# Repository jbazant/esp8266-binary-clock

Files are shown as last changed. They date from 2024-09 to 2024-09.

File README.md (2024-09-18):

# WEMOS D1 mini Binary clock

This is a private project. No support is provided. No input expected. Also as soon as I finish 1st version, I will
probably not work on it anymore.

Esp8266 based, IKEA Skadis mounted, NTP synchronized, "smart" binary clock with temperature and humidity sensor.

Binary clock based on a WEMOS D1 mini and a 8x8 LED matrix. Shows the seconds, minutes, hours, day in month, day in
week, month, lunar phase and last two decimal digits of year in binary format.
Also uses a DHT sensor to show the temperature and humidity.
Time is synchronized via NTP.

Two buttons allow to disable display and set the brightness.

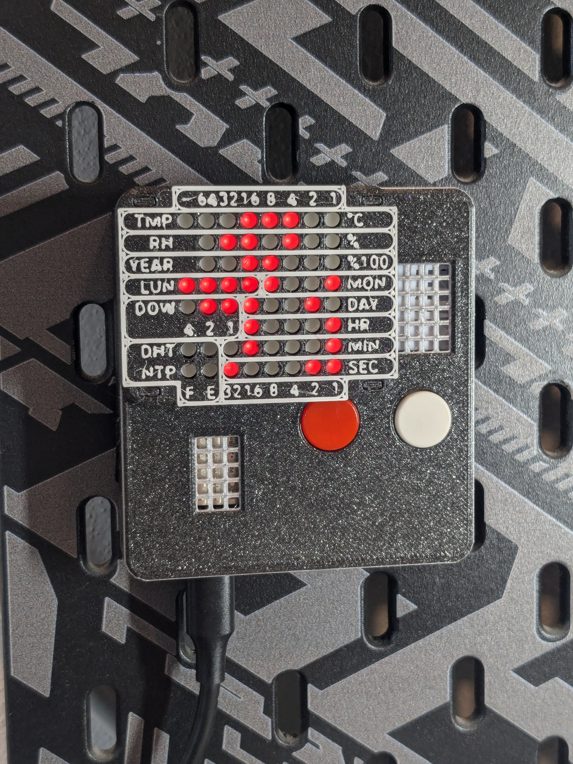
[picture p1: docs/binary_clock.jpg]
Binary clock


## How to read the clock

- Columns correspond to bits. Read them as (from right to left): 1, 2, 4, 8, 16, 32, 64.
- 8th bit is used for temperature as a sign bit (0 - positive, 1 - negative).
- Some rows have different meaning for top-most bits, but it should be obvious, once you get the idea.
- Labels on display cover should guide you.

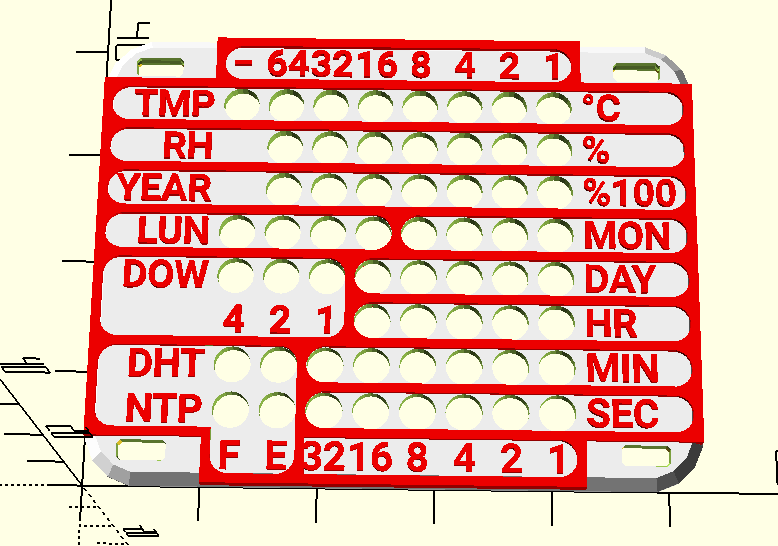
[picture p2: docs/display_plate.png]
Cover with labels


### Rows

Rows from top to bottom:

- **1st row**: temperature (in Celsius) - 8th bit is a sign bit (0 - positive, 1 - negative)
- **2nd row**: relative humidity (in %) - 8th bit is not used (and it is also not visible on the display)
- **3rd row**: years - last two decimal digits (or year % 100, if you prefer), 8th bit is not used
  plate place is occupied by temperature labels)
- **4th row**:
    - Bits 1 - 4: months (1 = January, 12 = December)
    - Bits 5 - 8: lunar phase (see description below)
- **5th row**:
    - Bits 1 - 5: day in month
    - Bits 6 - 8: day of week - read from right to left - 6th bit means 1, 8th bit means 4 (1 = Monday, 7 = Sunday)
- **6th row**:
    - Bits 1 - 5: hours (24h format)
    - Bits 6 - 8: not used (and on the display plate place is occupied by day of week labels)
- **7th row**:
    - Bits 1 - 6: minutes
    - Bits 7 - 8: status bits for DHT sensor. 7 - last read failed (**E**rror), 8 - reading sensor in progress (**F**
      etching)
- **8th row**:
    - Bits 1 - 6: seconds
    - Bits 7 - 8: status bits for NTP synchronization. 7 - last synchronization failed (**E**rror), 8 - time
      synchronization in progress (**F**etching)

### Lunar phase

| Bits 5 - 8 | Lunar phase | 🌝 |
|---|---|----|
| 0000 | New moon | 🌑 |
| 0001 | Waxing crescent | 🌒 |
| 0011 | First quarter | 🌓 |
| 0111 | Waxing gibbous  | 🌔 |
| 1111 | Full moon | 🌕 |
| 1110 | Waning gibbous  | 🌖 |
| 1100 | Last quarter | 🌗 |
| 1000 | Waning crescent | 🌘 |

Photo of the clock shows: Wednesday, 18th of September 2024, 12:17:35, full moon, 28°C, 52% relative humidity.

## Hardware

- WEMOS D1 mini
- 8x8 LED matrix with MAX7219 controller (FC-16)
- DHT22 sensor
- 2 buttons
- 4 pull-up 10kOhm resistors (2 for the buttons, 1 for the DHT sensor and 1 for reset pin)

## Software

The software is written as arduino project mostly in C++ and can be found in the `esp8266-binary-clock` folder (to
satisfy arduino project structure).

### Dependencies

- **DHT library** by Bert Melis ([GitHub](https://github.com/bertmelis/DHT))
- **NTP library** by Stefan Staub ([GitHub](https://github.com/sstaub/NTP))
- **LedController** library by Noah Kirschmann ([GitHub](https://github.com/noah1510/LedController))
- **moonPhaser** library by Steve Sienkowski ([GitHub](https://github.com/steve-sienk/moonPhaser-avr0))

### Configuration

- Create `secrets.h` in the `esp8266-binary-clock` and specify your WiFi credentials. (see `secrets.h.example`)
- Adjust `CONFIGURATION` section and `initTimezoneAndDST` method in `esp8266-binary-clock.ino` to your needs (or just
  leave as is).
    - `DHT_INTERVAL_S` - interval for reading DHT sensor (in seconds), default 1 minute
    - `NTP_INTERVAL_S` - interval for NTP synchronization (in seconds), default 12 hours

## PCB

The PCB is designed in KiCad and can be found in the `pcb` folder. Size of the PCB board is 66 x58 mm with LED matrix
and DHT22 sensor overhanging the board.
Board is actually pretty simple and uses just one Cu layer and 0.5mm clearance between tracks. You need to use 1.6mm PCB
thickness or adjust the case (bottom part).

## Case

The case is designed in OpenScad and can be found in the `case` folder. Optimized (well as much as I was able to...) for
FDM 3D printing.

- optimized for 0.4mm nozzle and 0.2mm layer height
- tested with PLA
- no supports
- 2 perimeters and 15% infill is more than enough

Case is divided into 3 parts:

- bottom (`case_bottom.scad`)
- top (`case_top.scad`)
- display cover (`display_plate.scad`)

One can render all parts with the `case.scad` file.

All the parts should snap together without any screws or glue.

### Dependencies

- **BOSL library** by Revar Desmera ([GitHub](https://github.com/revarbat/BOSL)).
- **Roboto** (bold) font by Christian Robertson ([Google fonts](https://fonts.google.com/specimen/Roboto0)).

### Case bottom

Case is printed with supports that are included in the model. Do not add supports in slicer! After printing, remove
the "triangle" simply by tilting it back and forth
and "mouse ears" with a knife.

Assembled PCB (optimized for 1.6mm height) should fit into the model without any screws or glue. Some force is needed to
snap it in.

### Case top

- *(Optional)* color change at heights:
    - Start with color for "ventilation" grids.
    - Change color at 1.4mm for the base one.

### Display cover

- Use some pretty contrast colors for the display cover. Change filament color at the height of 1.2mm.
- *(Optional)* Use nozzle of 0.25mm for better readability of the labels.

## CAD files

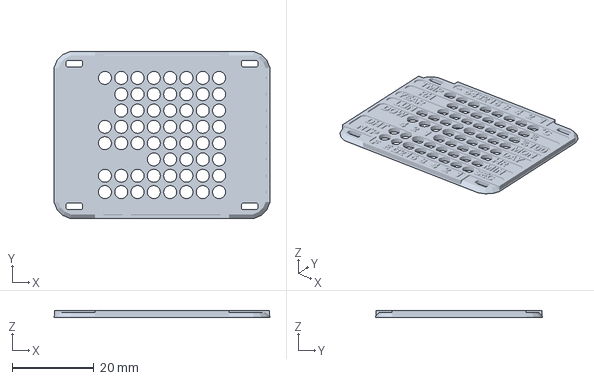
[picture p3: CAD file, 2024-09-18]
case/display_plate.3mf
53.0 x 41.0 x 1.60 mm

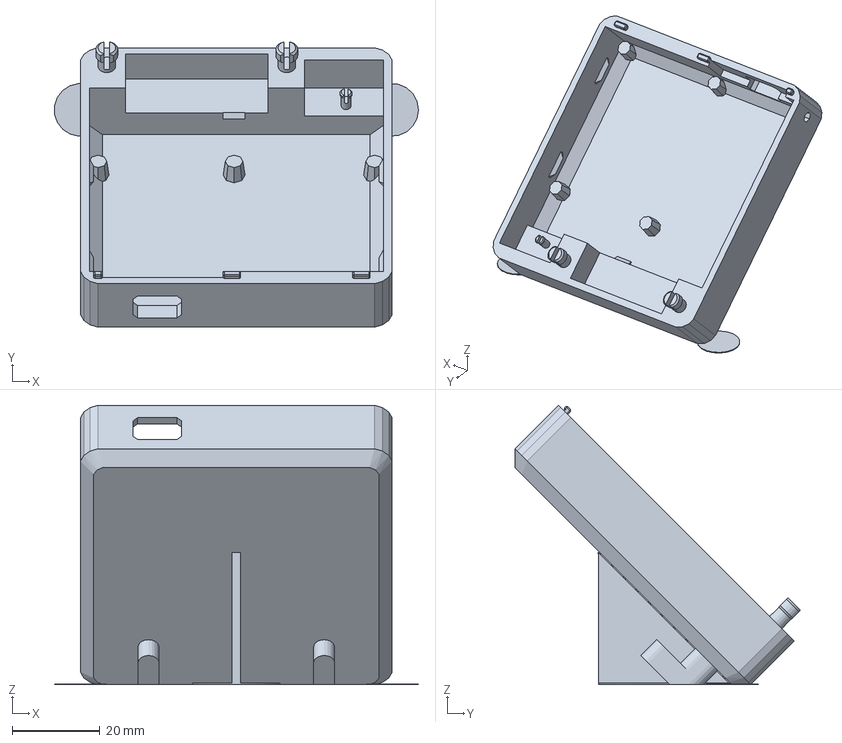
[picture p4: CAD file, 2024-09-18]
case/case_bottom.3mf
82.9 x 65.0 x 63.6 mm

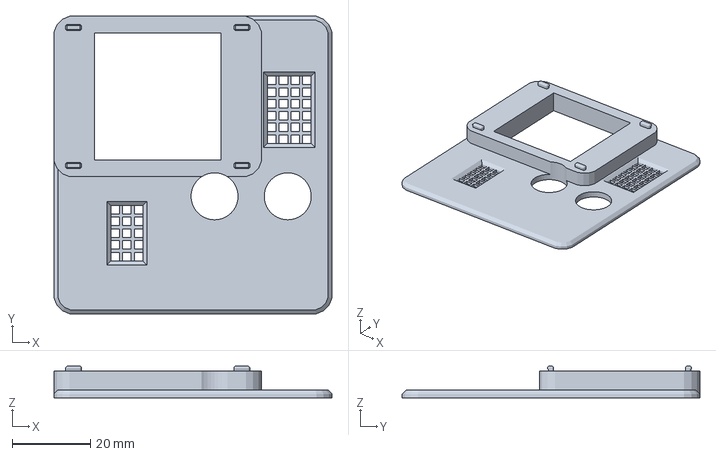
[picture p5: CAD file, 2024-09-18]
case/case_top.3mf
71.0 x 76.0 x 8.10 mm

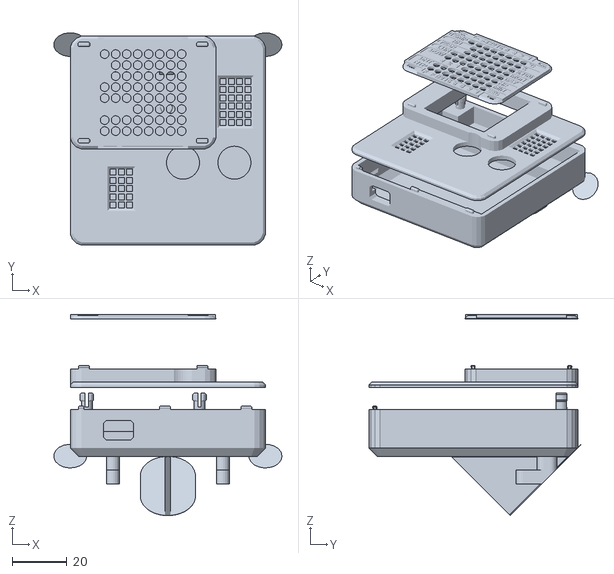
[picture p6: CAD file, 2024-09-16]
case/case.stl
82.9 x 77.2 x 73.2

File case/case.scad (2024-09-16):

use <BOSL/transforms.scad>
use <case_top.scad>
use <case_bottom.scad>
use <display_plate.scad>

// --- global configuration ---
// (actually do not mess with it)
w=71;
l=76;
f=5;

// --- render ---
zdistribute(25) {
    case_bottom(w, l, f);
    case_top(w, l, f);
    translate([0, 35, -10]) display_plate(f, "Roboto:style=Bold");
}

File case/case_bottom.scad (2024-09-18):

include <BOSL/constants.scad>
use <BOSL/transforms.scad>
use <BOSL/shapes.scad>
include <skadis.scad>
use <locks.scad>

// --- global configuration ---
// (actually do not mess with it)
w=71;
l=76;
f=5;

// --- render ---
xrot(-45) 
    case_bottom(w, l, f);

// --- modules ----
module case_bottom(w, l, f) {
    h1=8;
    h2=9;
    pcb_l=59;
    pcb_w=w-4;
    
    module custom_print_support() {
        color([.5, .5, .5], .7) union() {
            translate([w/2, 3*l/4, 0]) {
                translate([0, 5, 10.3]) rotate([45, 0, 180])         
                    right_triangle(
                        [2, 30, 30], 
                        orient=ORIENT_X, align=V_DOWN
                    );
                
                for (ty=[-l/3 : 4 : l/4]) {
                    translate([0, ty, 1]) xrot(-45) 
                        downcube([.8, .4, 2]);
                }
            }
            translate([0, l-3, 0]) xrot(45)
                translate([w/2, -15.5, .4]) cuboid(
                    [20, 30, .4], 
                    align=V_BOTTOM, 
                    fillet=10, edges=EDGES_Z_ALL
                );
            
            translate([0, l-3, 0]) xrot(45) {
                cylinder(d=12, h=.2);
                translate([w, 0, 0]) cylinder(d=12, h=.2);
            }
        }
    }
    
    module print_bad_boundary() {
        translate([w/2, l-3, 0]) xrot(45) downcube([w, l*3, 10]);
    }
    
    module pcb_stands() {
        for (tx=[4, 35, w-4]) {
            for (ty=[6, 50]) {
                translate([tx, ty, 2]) cylinder(r1=2.5, r2=2, h=h1-2-1.6);
            }
        }
    }
        
    module pcb_locks() {
        module single_lock_y() {
            translate([0, 0, h1+.1]) hull() {
                cuboid([1, 8, 1], align=V_LEFT+V_UP);
                translate([0, -2.5, 0]) 
                    right_triangle([1, 5, 1], orient=ORIENT_Y);
            }
        }
        
        module single_lock_x() {
            translate([-2.5, 0, h1+.1]) right_triangle([5, 1, 1], orient=ORIENT_X);
        }
        
        translate([2, pcb_l/4, 0]) single_lock_y();
        translate([2, 3*pcb_l/4, 0]) single_lock_y();
        translate([pcb_w+2, pcb_l/4, 0]) zrot(180) single_lock_y();
        translate([pcb_w+2, 3*pcb_l/4, 0]) zrot(180) single_lock_y();
        translate([35, pcb_l+4, 0]) zrot(180) single_lock_x();
    }
    
    module case_bottom_hull() {
        difference() {
            // base mass
            hull() {
                cuboid(
                    [w-6, l-6, 1], 
                    p1=[3, 3, 0],
                    fillet=f-2, edges=EDGES_Z_ALL
                );
                cuboid(
                    [w, l, h1+h2-3], 
                    p1=[0, 0, 3],
                    fillet=f, edges=EDGES_Z_ALL
                );
            }
            
            // base hole
            cuboid([
                pcb_w, pcb_l, h1+h2], 
                p1=[2, 4, 2],
                chamfer=3, edges=EDGES_BOTTOM-EDGE_BOT_BK );
            
            // usb hole
            cuboid([11, 10, 7], p1=[12, -1, h1-2], chamfer=1);
            
            // wemos hole
            cuboid([27.5, 35, h2], p1=[5, 2, h1+1]);
            
            // reset hole
            translate([-1, 6, h1+2]) yrot(90)
                cylinder(r=1.5, h=10, $fn=6);
            
            // fc-16 hole
            cuboid([32.4, 20, h2], p1=[10.3, l-22, h1+1]);
            
            // DHT hole
            cuboid([18, 20, h2+1], p1=[51, l-24, h1]);
        }
    }
    
    module skadis_mount() {
        translate([w/2, l-10, -10]) zrot(-90)
            skadis_hook_double();
    }
    
    module dht_lock() {
        color("blue") translate([pcb_w+2-8.5, pcb_l+4+3.2, h1]) lock_cylindric_small();
    }
    
    module locks() {
        // translations should have same x and y as for top case
        translate([4, 2.3, h1+h2]) zrot(-90) lock_micro_narrow();
        translate([34.5, 2.3, h1+h2]) zrot(-90) lock_micro();
        translate([64, 2.3, h1+h2]) zrot(-90) lock_micro();
        translate([6, 70, h1+h2]) lock_cylindric();
        translate([47, 70, h1+h2]) lock_cylindric();
    }
    
    difference() {
        union() {
            case_bottom_hull();
            pcb_stands();
            pcb_locks();
            skadis_mount();
            custom_print_support();
            dht_lock();
            locks();
        }
        
        print_bad_boundary();
    }
}

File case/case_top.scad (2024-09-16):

include <BOSL/constants.scad>
use <BOSL/transforms.scad>
use <BOSL/shapes.scad>
use <locks.scad>

// --- global configuration ---
// (actually do not mess with it)
w=71;
l=76;
f=5;

// --- render ---
case_top(w, l, f);

// --- modules ----
module case_top(w, l, f) {
    module display_housing() {
        module display_walls() {
            translate([10.5, 4.5, 0]) difference() {
                cuboid(
                    [53, 41, 6.8], 
                    p1=[-10.5, -4.5, 0],
                    edges=EDGES_Z_ALL, 
                    fillet=f 
                );
                translate([-.2, -.2, -1]) cube([32.4, 32.4, 10]);
            }
        }
        
        module display_locks() {
            translate([0, 0, 6.8]) {
                // translations should have same x and y as for "display plate"
                translate([5, 3, 0]) zrot(-90) lock_micro();
                translate([48, 3, 0]) zrot(-90) lock_micro();
                translate([5, 38, 0]) zrot(90) lock_micro();
                translate([48, 38, 0]) zrot(90) lock_micro();
            }
        }
        
        union() {
            display_walls();
            display_locks();
        }
    }
        
    module top_plate() {
        module grid(x, y, w, l) {
            hull() {
                translate([x, y, 1]) cube([w, l, 2]);
                translate([x-1, y-1, 2]) cube([w+2, l+2, 1]);
            }
            for (tx=[x : 3 : x+w-1]) {
                for (ty=[y : 3 : y+l-1]) {
                    translate([tx, ty, -1]) cube([2.2, 2.2, 4]);
                }
            }
        }
        
        module dht_grid() {
            grid(54.5, 43.5, 11.2, 17.2);
        }
        
        module wemos_grid() {
            grid(14.5, 13.5, 8.2, 14.2);
        }
        
        difference() {
            hull() {
                cuboid(
                    [w, l, 1], p1=[0, 0, 0],
                    edges=EDGES_Z_ALL, fillet=f 
                );
                cuboid(
                    [w-2, l-2, 2], p1=[1, 1, 0],
                    edges=EDGES_Z_ALL, fillet=f-1
                );
            }
            
            // display housing (difference)
            cuboid(
                [53, 41, 10], p1=[0, 35, -3],
                edges=EDGES_Z_ALL, fillet=f 
            );
            
            dht_grid();
            wemos_grid();
        }  
    }

    module button_hole() {
        cylinder(r=6, h=20, $fn=40);
    }
    
    module button_holes() {
        translate([41, 30, -3]) button_hole();
        translate([59.7, 30, -3]) button_hole();
    }
    
    module locks() {
        // translations should have same x and y as for bottom case
        translate([4, 2.3, 0]) zrot(-90) lock_micro_narrow_housing();
        translate([34.5, 2.3, 0]) zrot(-90) lock_micro_housing();
        translate([64, 2.3, 0]) zrot(-90) lock_micro_housing();
        translate([6, 70, 0]) lock_cylindric_housing();
        translate([47, 70, 0]) lock_cylindric_housing();
    }
    
    difference() {
        union() {
            top_plate();
            translate([0, 35, 0]) display_housing();
        }
        button_holes();
        color("red") locks();
    }
}

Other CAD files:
case/display_plate.scad
case/case_bottom.stl
case/case_top.stl
case/display_plate.stl
case/locks.scad
case/skadis.scad

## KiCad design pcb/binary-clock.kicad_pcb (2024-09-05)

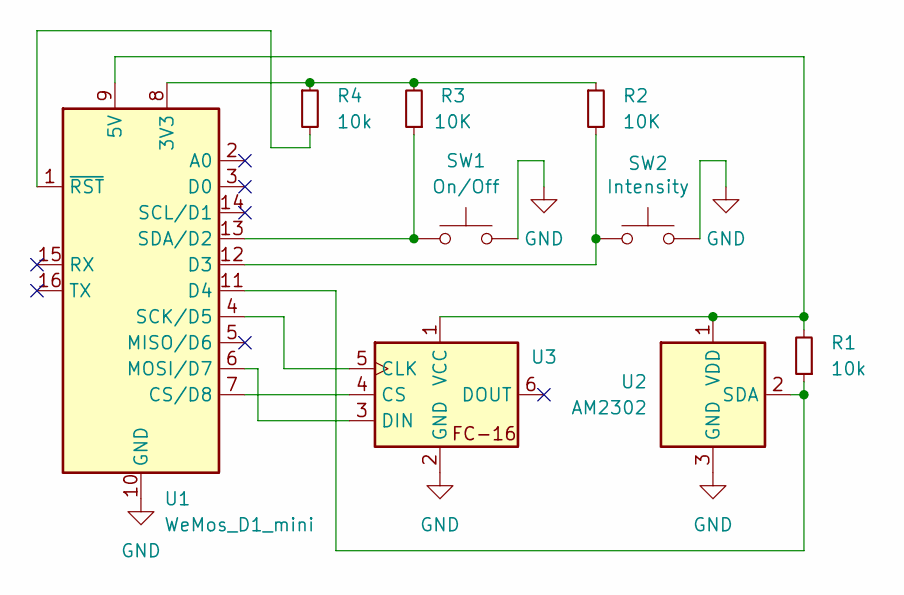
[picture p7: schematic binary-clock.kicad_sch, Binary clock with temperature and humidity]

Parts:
R1, R4: 10k; R_Axial_DIN0207_L6.3mm_D2.5mm_P10.16mm_Horizontal
R2, R3: 10K; R_Axial_DIN0207_L6.3mm_D2.5mm_P10.16mm_Horizontal
SW1: On/Off; SW_PUSH-12mm
SW2: Intensity; SW_PUSH-12mm
U1: WeMos_D1_mini; WEMOS_D1_mini_light
U2: AM2302; ASAIR_AM2302_P2.54mm_Lead2.75mm_TabDown
U3: FC-16

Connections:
GND: SW1.2, SW2.2, U1.10 (GND), U2.3 (GND), U2.4 (GND), U3.2 (GND)
unnamed: R2.1, R3.2, R4.1, U1.8 (3V3)
unnamed: R1.2, U1.9 (5V), U2.1 (VDD), U3.1 (VCC)
unnamed: U1.7 (CS/D8), U3.4 (CS)
unnamed: R2.2, SW2.1, U1.12 (D3)
unnamed: R1.1, U1.11 (D4), U2.2 (SDA)
unnamed: U1.6 (MOSI/D7), U3.3 (DIN)
unnamed: U1.4 (SCK/D5), U3.5 (CLK)
unnamed: R3.1, SW1.1, U1.13 (SDA/D2)
unnamed: R4.2, U1.1 (~RST)

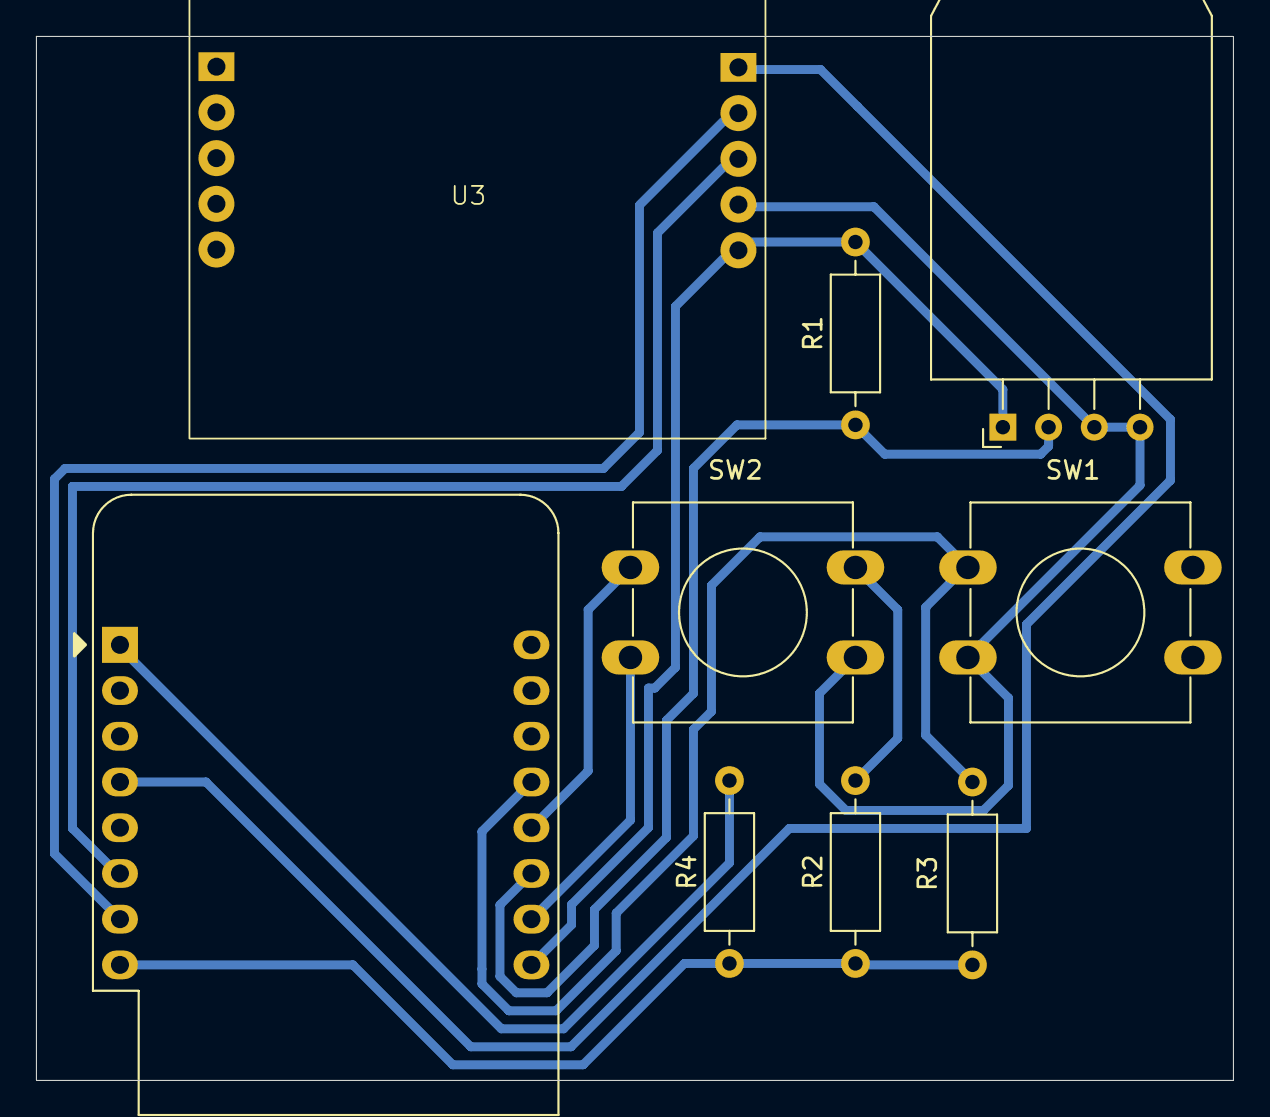
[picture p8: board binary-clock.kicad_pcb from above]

Board: 2 copper layers, 66.5 x 58.0 mm, 9 parts (0 on the bottom side), 10 nets.

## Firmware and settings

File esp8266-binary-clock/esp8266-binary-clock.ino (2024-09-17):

#include "LedController.hpp"
#include "MyDHT.h"
#include "Buttons.h"
#include "ClockDisplay.h"
#include "MyNTPClient.h"
#include "WithTicker.h"
#include "TickerController.h"
#include "secrets.h"

// ------------------------- CONFIGURATION -------------------------
#define REFRESH_RATE_MS 250

// NTP
#define NTP_SERVER "europe.pool.ntp.org"
#define NTP_INTERVAL_S 12 * 3600

// DHT
#define DHT_PIN D4
#define DHT_INTERVAL_S 60

// BUTTONS
#define INTENSITY_BUTTON_PIN D3
#define ON_OFF_BUTTON_PIN D2
#define BUTTONS_READ_INTERVAL_MS 500

// DISPLAY
#define DIN_PIN D7
#define CLK_PIN D5
#define CS_PIN D8

// ------------------------- GLOBAL OBJECTS -------------------------

MyNTPClient ntpClient(NTP_SERVER, WIFI_SSID, WIFI_PASSWORD, NTP_INTERVAL_S);
MyDHT dhtSensor(DHT_PIN, DHT_INTERVAL_S);
Buttons buttons(INTENSITY_BUTTON_PIN, ON_OFF_BUTTON_PIN, BUTTONS_READ_INTERVAL_MS);
ClockDisplay display(DIN_PIN, CLK_PIN, CS_PIN, &dhtSensor, &ntpClient, REFRESH_RATE_MS);
TickerController tickerController;

// ------------------------- PROGRAM LOGIC -------------------------
void initTimezoneAndDST() {
    ntpClient.ruleDST("CEST", Last, Sun, Mar, 2, 120); // last sunday in march 2:00, timetone +120min (+1 GMT + 1h summertime offset)
    ntpClient.ruleSTD("CET", Last, Sun, Oct, 3, 60); // last sunday in october 3:00, timezone +60min (+1 GMT)
}

void changeIntensity() {
    display.changeIntensity();
}

void switchSegment() {
    display.switchSegment();
}

void initSerial() {
    Serial.begin(9600);
    Serial.println("");
    Serial.println("-------------");
}

void registerTickers() {
    tickerController.addTicker(&ntpClient);
    tickerController.addTicker(&dhtSensor);
    tickerController.addTicker(&buttons);
    tickerController.addTicker(&display);
}

void setup() {
    initSerial();
    Serial.println("Initializing:");

  	display.renderLoading();

    buttons.onIntensityPressed(changeIntensity);
    buttons.onOnOffPressed(switchSegment);

    initTimezoneAndDST();
    ntpClient.syncTimeSync();

    registerTickers();
    tickerController.startAllTickers();

    Serial.println("Initialized");
}

void loop() {
    tickerController.onTimeAdvanced();
    // note that this is a smallest delay possible, all ticker must be multiples of this delay
    delay(REFRESH_RATE_MS);
}

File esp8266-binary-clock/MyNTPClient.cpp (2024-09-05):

#include "MyNTPClient.h"

#define WIFI_CONN_TIMEOUT 30000
#define WIFI_CONN_TICK 1000

MyNTPClient::MyNTPClient(const char* ntpServer, const char* ssid, const char* password, const uint interval)
    : NTP(wifiUdp_), WithTicker(interval * 1000), isSyncing_(false), hasError_(false), ntpServer_(ntpServer),
      ssid_(ssid), password_(password), defaultSyncInterval_(interval * 1000), wifiSyncInterval_(WIFI_CONN_TICK)
{}

bool MyNTPClient::isSyncing() {
  return this->isSyncing_;
}

bool MyNTPClient::hasError() {
  return this->hasError_;
}

void MyNTPClient::syncTimeAsync() {
    this->isSyncing_ = true;
    this->setInterval(this->wifiSyncInterval_);

    // Connect to WiFi and wait for connection
    this->connectToWiFi_();
}

void MyNTPClient::syncTimeSync() {
    this->isSyncing_ = true;
    this->connectToWiFi_();
    this->waitForWiFiSync_();
    this->onWifiConnectionResolved();
}

void MyNTPClient::onTick() {
  	if (this->isSyncing_) {
    	this->onWifiConnectTick();
  	} else {
    	this->syncTimeAsync();
  	}
}

void MyNTPClient::onWifiConnectTick() {
  	bool keepPolling = this->checkWiFiStatus_();
    if (!keepPolling) {
        this->onWifiConnectionResolved();
    }
}

void MyNTPClient::connectToWiFi_() {
    Serial.print("Connecting to WiFi: ");
    WiFi.begin(this->ssid_, this->password_);
    this->pollRetries_ = WIFI_CONN_TIMEOUT / WIFI_CONN_TICK;
}

void MyNTPClient::waitForWiFiSync_() {
	while (this->checkWiFiStatus_()) {
      	delay(WIFI_CONN_TICK);
    }
}

bool MyNTPClient::checkWiFiStatus_() {
    bool keepPolling = true;

    // https://realglitch.com/2018/07/arduino-wifi-status-codes/
    switch (WiFi.status()) {
        case WL_CONNECTED:
            this->hasError_ = false;
            Serial.println("Connected");
            keepPolling = false;
            break;

        case WL_NO_SSID_AVAIL:
            this->hasError_ = true;
            Serial.println("No SSID available");
            keepPolling = false;
            break;

        case WL_CONNECT_FAILED:
            this->hasError_ = true;
            Serial.println("Connection failed");
            keepPolling = false;
            break;

        case WL_NO_SHIELD:
            this->hasError_ = true;
            Serial.println("No shield");
            keepPolling = false;
            break;

        default:
            Serial.print(WiFi.status());
            Serial.print("-");
            break;
    }

    return keepPolling && this->pollRetries_-- > 0;
}

void MyNTPClient::onWifiConnectionResolved() {
    // if WiFi is connected, sync time
    if (!this->hasError_) {
        this->syncTime_();
    }

    this->disconnectFromWiFi_();
    this->isSyncing_ = false;
    this->setInterval(this->defaultSyncInterval_);
}

void MyNTPClient::disconnectFromWiFi_() {
    WiFi.disconnect();
    WiFi.mode(WIFI_OFF);
    Serial.println("Disconnected from WiFi");
}

void MyNTPClient::syncTime_() {
    Serial.println("Syncing time");
    this->begin(this->ntpServer_);

    Serial.print("Time synced: ");
    Serial.println(this->formattedTime("%T %A, %d. %B %Y"));
}

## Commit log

2024-08-29 fix button mismatch
2024-08-30 Improve MyNTPClient error handling, refactoring
    [MyNTPClient.cpp, esp8266-binary-clock.ino]
2024-08-30 WIP: case OpenScad model - display plate first candidate
    [case.scad, display_plate.stl]
2024-09-05 PCB prototype in KiCad
    [binary-clock.kicad_pcb, binary-clock.kicad_sch]
2024-09-05 fix: Fix crash on NTP sync by introducing own Ticker implementation
    [MyNTPClient.cpp, esp8266-binary-clock.ino]
2024-09-16 feat: case - basic version
    [case.3mf, case.scad, case.stl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]
2024-09-16 chore: better and separate .3mf files
    [case.3mf, case_bottom.3mf, case_top.3mf]
2024-09-17 chore: adjust constants in arduino code
2024-09-18 chore: adjust lock tolerances
    [case_bottom.3mf, case_bottom.scad, case_bottom.stl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]
